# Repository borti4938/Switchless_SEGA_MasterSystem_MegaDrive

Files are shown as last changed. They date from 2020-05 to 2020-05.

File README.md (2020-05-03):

### Switchless Mods for SEGA MasterSystem and MegaDrive
---

This is a collection of earlier projects. These projects are not under development anymore. Documentation is rather simple and can be found in source code comments in most cases.

Please don't write me for any support. Please reach out to community forums and use the knowledge and experiences there.

Best Regards, Peter

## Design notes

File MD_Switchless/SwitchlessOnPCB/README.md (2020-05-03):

This small subprject is not initialted be myself. All thanks to this go to user _ArcadeTV_ and user _wshadow_; both members of the [Circuit-Board.de](https://circuit-board.de/forum/) community.
So what is this?

Histroy
---

Once I started designing my own switchless mod for the Sega Mega Drive, ArcadeTV drew a printed circuit board.
Although I was not ready with the implementation, ArcadeTV [published the PCB on circuit-board](https://circuit-board.de/forum/index.php/Thread/14691-Mega-Drive-Mod-Platinen-RGB-Bypass-Switchless-Mod-Mega-Amp/).  
This board is available in this repository.

Time was running and I lost the focus to this PCB.
Instead I made design decisions which made PCB pinout incompatible to my code.
Reasons were being pin compatible to [Sebs popular code](https://knzl.at/saturnmod/), which is used for Multi-BIOS extension on the MegaCD as well as the [build-in-game project](https://github.com/borti4938/MD-Build-In-Game).
The code went into a final state as it is presented in the top-folder here in the repository.
Another long time period passed by.

CiBo user wshadow [picked up both](https://circuit-board.de/forum/index.php/Thread/14691-Mega-Drive-Mod-Platinen-RGB-Bypass-Switchless-Mod-Mega-Amp/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) - the PCB and code - and made both compatible again.
He worked hard, learned assembler, and finally made it.
I reviewed the changes and now publish code and PCB.

Notes
---

I don't own a Mega Drive!
So please be patient if there are any misstakes in the text comming from my misunderstanding.

### PCB

PCB is made with EAGLE and has two layers.
I tested to upload the PCB on OSHPark and it works.
Of course, you can also use any other PCB manufacturer you want.

### Parts for PCB and Installation

- 1x RND 1500805Y1041
- 1x BAT 54A SMD
- 1x PIC 16F630-I/SL
- 2x SMD-0805 1,0K
- 1x RND 0805 1 20K
- 2x SMD-0805 220
- 1x RG-LED or RGB-LED with 3mm or 5mm head  
  For installation, Code supports both common anode and common cathod LEDs

### Code

The code is made for the PIC16F630.
There is an ICSP header on the PCB.

### Additional notes

Additional notes can be found in the top comment section of the *.asm file.

### Feedback

Feedback is very welcome!

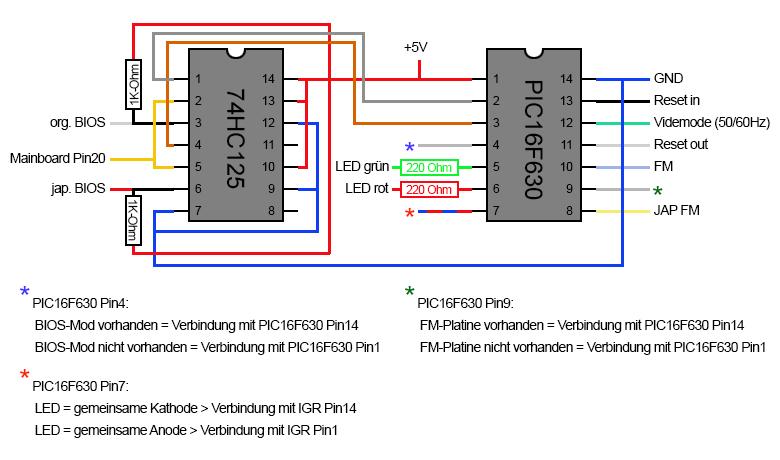
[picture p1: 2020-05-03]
MS_FM_BIOS/SMS-Mod.jpg

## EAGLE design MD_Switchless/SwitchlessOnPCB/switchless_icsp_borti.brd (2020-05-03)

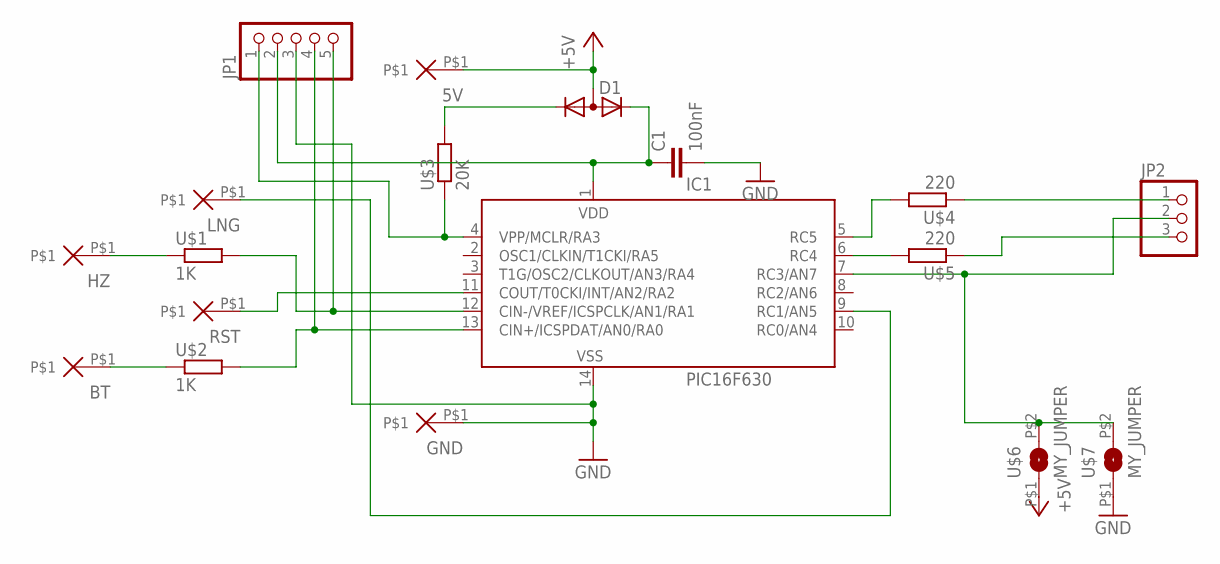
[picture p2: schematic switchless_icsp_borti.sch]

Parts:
5V: PAD; PADS
BT: PAD; PADS
C1: 100nF; Z0805
D1: DIODE_CA-AC__; SOT23C
GND: PAD; PADS
HZ: PAD; PADS
IC1: PIC16F630
JP1: PINHD-1X5; 1X05
JP2: PINHD-1X3; 1X03
LNG: PAD; PADS
RST: PAD; PADS
U$1, U$2: 1K; Z0805
U$3: 20K; Z0805
U$4, U$5: 220; Z0805
U$6, U$7: MY_JUMPER; MYJUMP

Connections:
+5V: 5V.P$1, D1.3 (A), U$6.P$1 (1)
GND: C1.2, GND.P$1, IC1.14 (VSS), JP1.3, U$7.P$1 (1)
unnamed: IC1.5 (RC5), U$4.2
unnamed: IC1.6 (RC4), U$5.2
unnamed: JP2.1, U$4.1
unnamed: JP2.3, U$5.1
unnamed: IC1.9 (RC1/AN5), LNG.P$1
unnamed: IC1.11 (COUT/T0CKI/INT/AN2/RA2), RST.P$1
unnamed: IC1.12 (CIN-/VREF/ICSPCLK/AN1/RA1), JP1.5, U$1.2
unnamed: IC1.13 (CIN+/ICSPDAT/AN0/RA0), JP1.4, U$2.2
unnamed: IC1.4 (VPP/MCLR/RA3), JP1.1, U$3.1
unnamed: HZ.P$1, U$1.1
unnamed: BT.P$1, U$2.1
unnamed: C1.1, D1.2 (K2), IC1.1 (VDD), JP1.2
unnamed: D1.1 (K1), U$3.2
unnamed: IC1.7 (RC3/AN7), JP2.2, U$6.P$2 (2), U$7.P$2 (2)

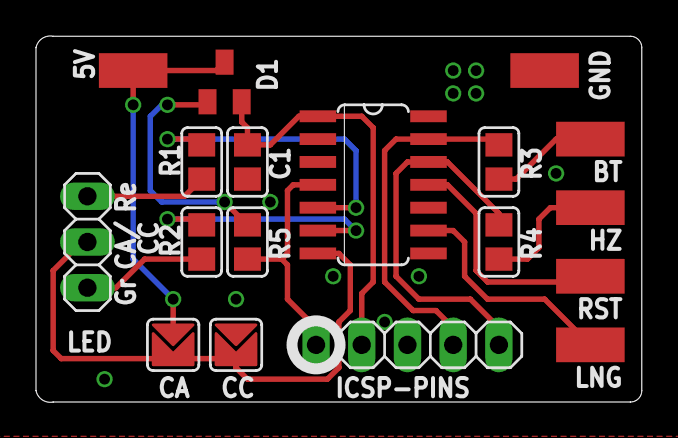
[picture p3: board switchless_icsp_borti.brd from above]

Board: 2 copper layers, 33.7 x 20.3 mm, 18 parts (0 on the bottom side), 16 nets.

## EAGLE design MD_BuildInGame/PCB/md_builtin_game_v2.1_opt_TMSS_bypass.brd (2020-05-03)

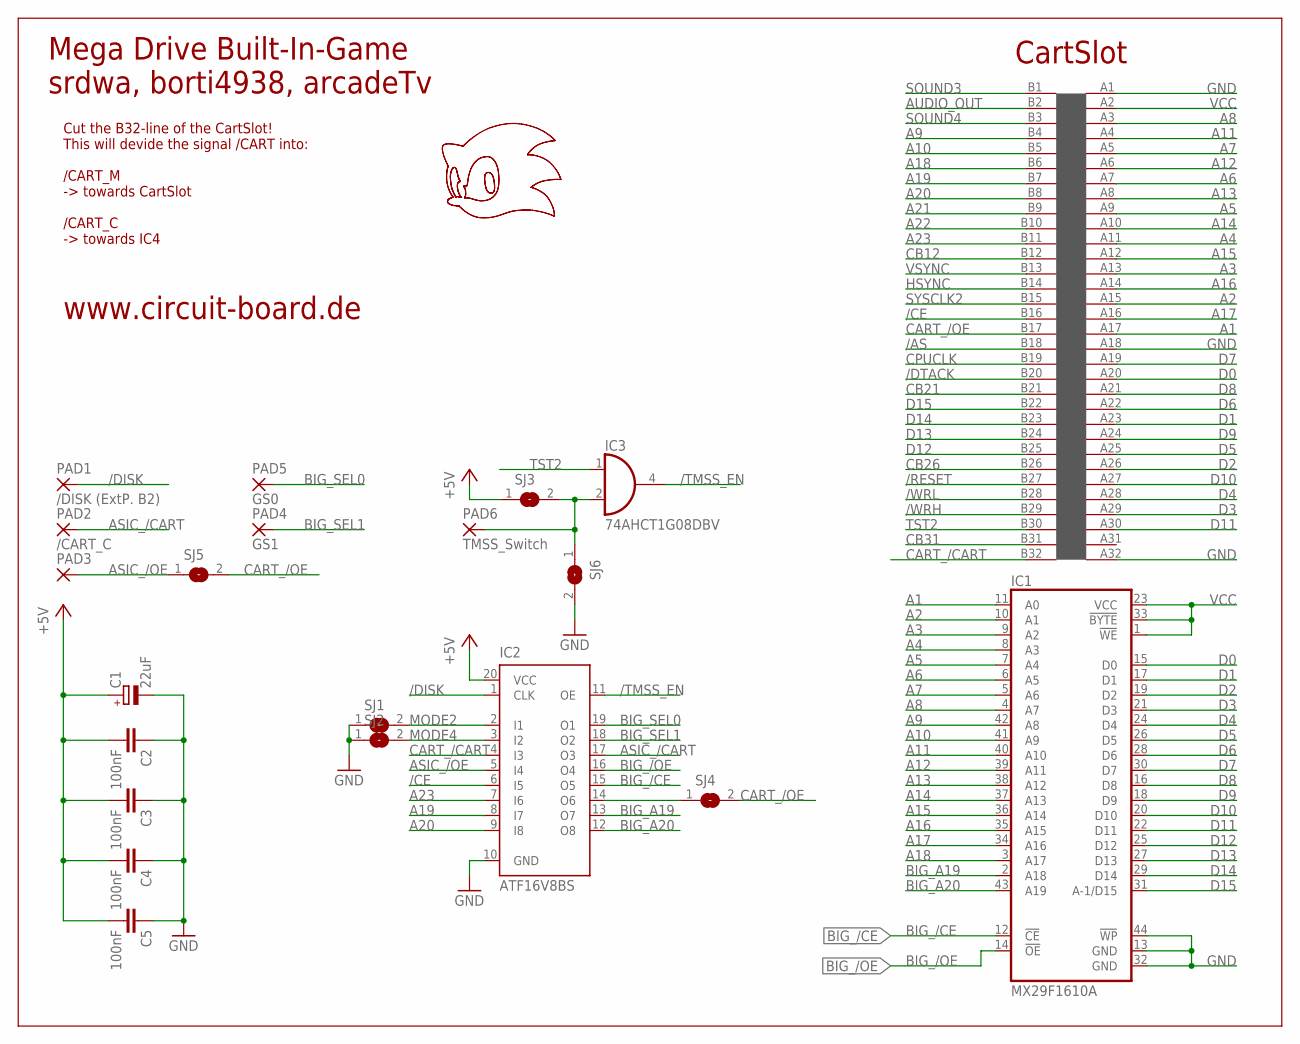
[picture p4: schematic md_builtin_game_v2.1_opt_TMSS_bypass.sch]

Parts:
C1: 22uF; SMC_C
C2, C3, C4, C5: 100nF; Z0805
IC1: MX29F1610A; SO44
IC2: ATF16V8BS; SO20L
IC3: 74AHCT1G08DBV; SOT23-5
PAD1: /DISK (ExtP. B2); SMD1,27-2,54
PAD2: /CART_C; SMD1,27-2,54
PAD3: SMD2; SMD1,27-2,54
PAD4: GS1; SMD1,27-2,54
PAD5: GS0; SMD1,27-2,54
PAD6: TMSS_Switch; SMD1,27-2,54
SJ1, SJ2, SJ3, SJ4, SJ5, SJ6: SJ
U$1: LOGO_SONIC_20MM
U$6: MEGADRIVE_EDGE_CONNECTOR

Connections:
/AS: U$6.B18
/CE: IC2.6 (I5), U$6.B16
/DISK: IC2.1 (CLK), PAD1.1
/DTACK: U$6.B20
/RESET: U$6.B27
/TMSS_EN: IC2.11 (OE), IC3.4 (O)
/WRH: U$6.B29
/WRL: U$6.B28
A1: IC1.11 (A0), U$6.A17
A2: IC1.10 (A1), U$6.A15
A3: IC1.9 (A2), U$6.A13
A4: IC1.8 (A3), U$6.A11
A5: IC1.7 (A4), U$6.A9
A6: IC1.6 (A5), U$6.A7
A7: IC1.5 (A6), U$6.A5
A8: IC1.4 (A7), U$6.A3
A9: IC1.42 (A8), U$6.B4
A10: IC1.41 (A9), U$6.B5
A11: IC1.40 (A10), U$6.A4
A12: IC1.39 (A11), U$6.A6
A13: IC1.38 (A12), U$6.A8
A14: IC1.37 (A13), U$6.A10
A15: IC1.36 (A14), U$6.A12
A16: IC1.35 (A15), U$6.A14
A17: IC1.34 (A16), U$6.A16
A18: IC1.3 (A17), U$6.B6
A19: IC2.8 (I7), U$6.B7
A20: IC2.9 (I8), U$6.B8
A21: U$6.B9
A22: U$6.B10
A23: IC2.7 (I6), U$6.B11
ASIC_/CART: IC2.17 (O3), PAD2.1
ASIC_/OE: IC2.5 (I4), PAD3.1, SJ5.1
AUDIO_OUT: U$6.B2
BIG_/CE: IC1.12 (!CE), IC2.15 (O5)
BIG_/OE: IC1.14 (!OE), IC2.16 (O4)
BIG_A19: IC1.2 (A18), IC2.13 (O7)
BIG_A20: IC1.43 (A19), IC2.12 (O8)
BIG_SEL0: IC2.19 (O1), PAD5.1
BIG_SEL1: IC2.18 (O2), PAD4.1
CART_/CART: IC2.4 (I3), U$6.B32
CART_/OE: SJ4.2, SJ5.2, U$6.B17
CB12: U$6.B12
CB21: U$6.B21
CB26: U$6.B26
CB31: U$6.B31
CPUCLK: U$6.B19
D0: IC1.15 (D0), U$6.A20
D1: IC1.17 (D1), U$6.A23
D2: IC1.19 (D2), U$6.A26
D3: IC1.21 (D3), U$6.A29
D4: IC1.24 (D4), U$6.A28
D5: IC1.26 (D5), U$6.A25
D6: IC1.28 (D6), U$6.A22
D7: IC1.30 (D7), U$6.A19
D8: IC1.16 (D8), U$6.A21
D9: IC1.18 (D9), U$6.A24
D10: IC1.20 (D10), U$6.A27
D11: IC1.22 (D11), U$6.A30
D12: IC1.25 (D12), U$6.B25
D13: IC1.27 (D13), U$6.B24
D14: IC1.29 (D14), U$6.B23
D15: IC1.31 (A-1/D15), U$6.B22
GND: C1.-, C2.1, C3.1, C4.1, C5.1, IC1.13 (GND), IC1.32 (GND), IC1.44 (!WP), IC2.10 (GND), IC3.3 (GND), SJ1.1, SJ2.1, SJ6.2, U$6.A1, U$6.A18, U$6.A32
HSYNC: U$6.B14
MODE2: IC2.2 (I1), SJ1.2
MODE4: IC2.3 (I2), SJ2.2
unnamed: IC2.14 (O6), SJ4.1
unnamed: IC3.2 (I1), PAD6.1, SJ3.2, SJ6.1
SOUND3: U$6.B1
SOUND4: U$6.B3
SYSCLK2: U$6.B15
TST2: IC3.1 (I0), U$6.B30
VCC: C1.+, C2.2, C3.2, C4.2, C5.2, IC1.1 (!WE), IC1.23 (VCC), IC1.33 (!BYTE), IC2.20 (VCC), IC3.5 (VCC), SJ3.1, U$6.A2
VSYNC: U$6.B13

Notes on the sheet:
Cut the B32-line of the CartSlot! This will devide the signal /CART into: /CART_M -> towards CartSlot /CART_C -> towards IC4
Mega Drive Built-In-Game srdwa, borti4938, arcadeTv
CartSlot
www.circuit-board.de

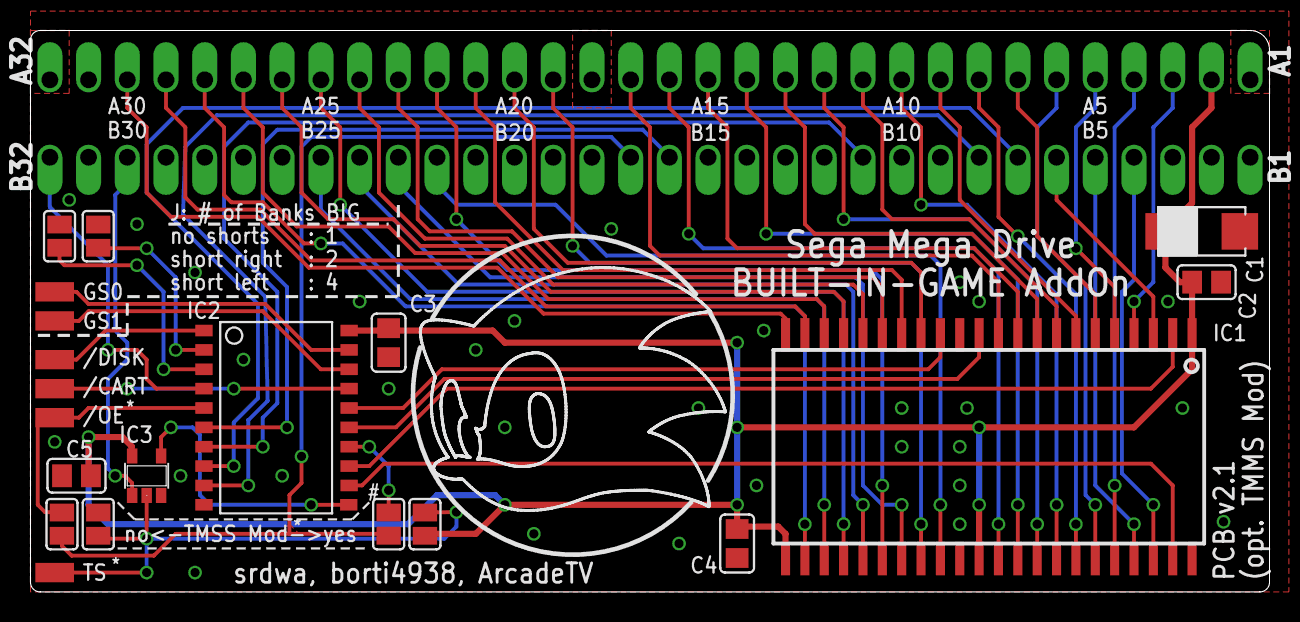
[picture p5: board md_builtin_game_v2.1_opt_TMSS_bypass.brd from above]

Board: 2 copper layers, 81.3 x 36.8 mm, 22 parts (0 on the bottom side), 57 nets.

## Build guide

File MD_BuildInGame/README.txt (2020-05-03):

Build-In Game Project for Sega Genesis / Mega Drive  
===================================================  
  
Main idea by ArcadeTV  
Development by srdwa, ArcadeTV and borti4938  
  
See logs and discussions here: http://circuit-board.de/forum/index.php/Thread/17706-Idee-Mega-Drive-mit-eingebautem-Spiel/  
  
===================================================  

This work here is still WIP!!! It has been never tested so far!!!  

===================================================  

Main idea:  
- start a game from internal rom if no device is present at the extension port or no cartridge is present  
- use indentification signals from cart slot and extension slot for detection  
- internal rom can be separated in one, two or four banks (selected by two pins)  
- bank switch is accessed by a 2bit counter  
- TMSS disable mod as described here: http://assemblergames.com/l/threads/md-genny-auto-switching-tmss-bypass-mod.19781/ can be enabled optionally  
  
===================================================  
  
ToDo:  
- test 2bit counter addition for switchless code (code by borti4938)  
- write installation tips  
  
===================================================  
  
Pinout of the PLD (G16V8) as used on the PCB:  
  
/* *************** INPUT PINS ******************** */  
PIN  1 = DISKn;     /* /DISK (ExpPort B2)                       */  
PIN  2 = ROM_Mode2; /* high/open = 1 game     , low = 2 games   */  
PIN  3 = ROM_Mode4; /* high/open = 1/2 game(s), low = 4 games   */  
                    /* low = 4 games (beats ROM_Mode2)          */  
PIN  4 = CARTn;     /* /CART (from ASIC cart slot B32,          */  
                    /*        cutted from ASIC)                 */  
PIN  5 = ASIC_OEn;  /* /OE (from ASIC; cutted from cart slot    */  
                    /*                 B17 if TMSS Mod is used) */  
PIN  6 = CEn;       /* /CE (cart slot B16)                      */  
PIN  7 = A23;       /* A23 (cart slot B11)                      */  
PIN  8 = AMSB0;     /* A19 (cart slot  B7)                      */  
PIN  9 = AMSB1;     /* A20 (cart slot  B8)                      */  
                    /* (addressbus counts from A1)              */  
  
/* *************** I/O PINS ******************** */  
PIN 19 = BIG_Sel0;   /* bank switch LSB                         */  
PIN 18 = BIG_Sel1;   /* bank switch MSB                         */  
PIN 17 = ASIC_CARTn; /* /CART (from ASIC; cutted from cart      */  
                     /*                   slot B32)             */  
PIN 16 = ROM_OEn;    /* /OE internal EEPROM (29F1610 Pin 14)    */  
PIN 15 = ROM_CEn;    /* /CE internal EEPROM (29F1610 Pin 12)    */  
PIN 14 = CART_OEn;   /* /OE cartridge (cart slot B17)           */  
PIN 13 = ROM_AMSB0;  /* A18 internal EEPROM (29F1610 Pin  2)    */  
PIN 12 = ROM_AMSB1;  /* A19 internal EEPROM (29F1610 Pin 43)    */  
PIN 11 = TMSS_ENn;   /* high = disabled, low = enabled          */  
                     /* /M3 (cart slot B30) AND TMSS-Mod_en     */

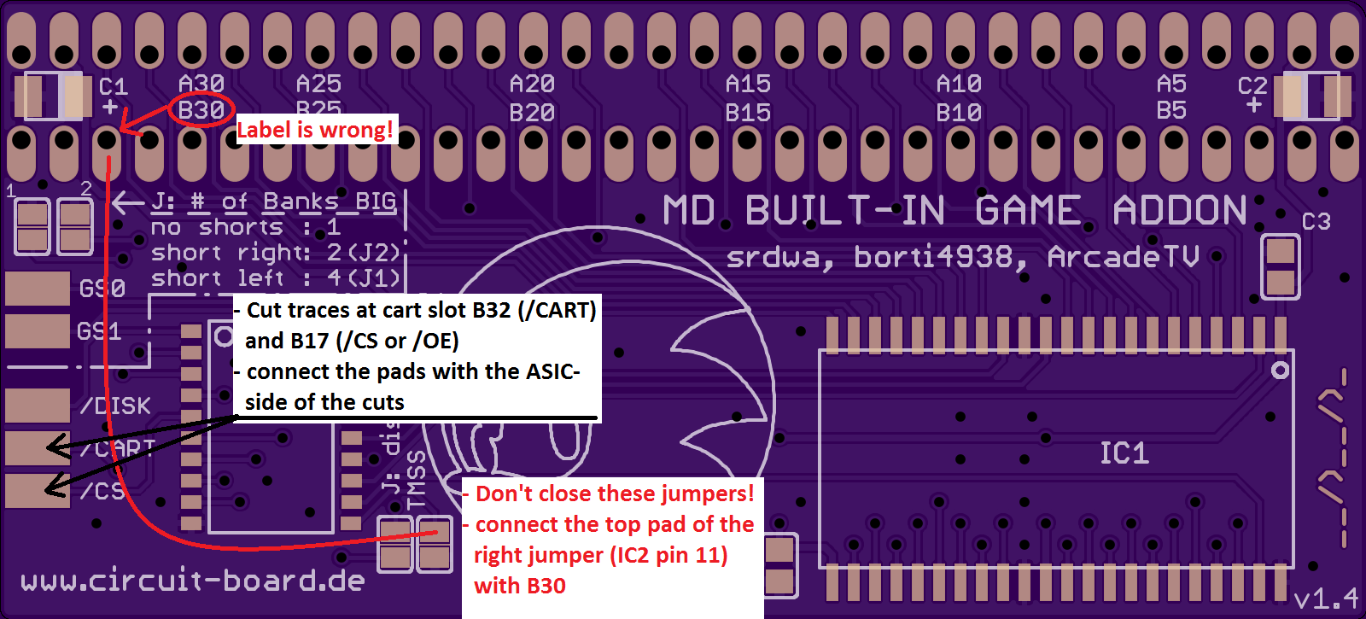
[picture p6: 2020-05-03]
MD_BuildInGame/PLD/Backup_Compatibility_PCB_V1.4/MD_BIG_V1.4_USE_TMSS_Bypass.png

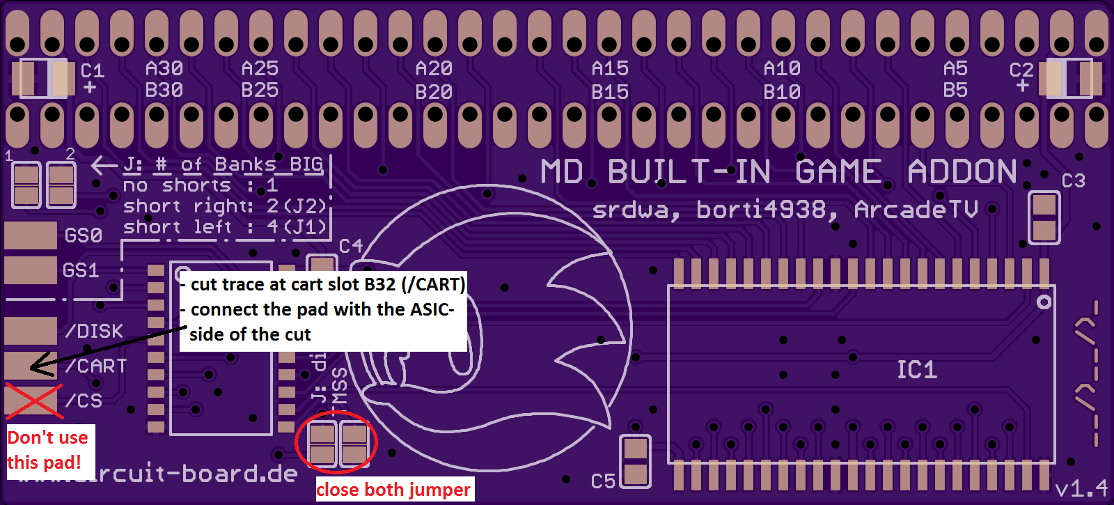
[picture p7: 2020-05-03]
MD_BuildInGame/PLD/Backup_Compatibility_PCB_V1.4/MD_BIG_V1.4_NO_TMSS_Bypass.png

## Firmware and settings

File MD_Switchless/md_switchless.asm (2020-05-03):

#include <p16f630.inc>

;
; -----------------------------------------------------------------------
;
;	Sega Mega Drive switchless mod
;
;   Copyright (C) 2016 by Peter Bartmann
;
;   This program is free software; you can redistribute it and/or modify
;   it under the terms of the GNU General Public License as published by
;   the Free Software Foundation; version 2 of the License only.
;
;   This program is distributed in the hope that it will be useful,
;   but WITHOUT ANY WARRANTY; without even the implied warranty of
;   MERCHANTABILITY or FITNESS FOR A PARTICULAR PURPOSE.  See the
;   GNU General Public License for more details.
;
;   You should have received a copy of the GNU General Public License
;   along with this program; if not, write to the Free Software
;   Foundation, Inc., 59 Temple Place, Suite 330, Boston, MA  02111-1307  USA
;
; -----------------------------------------------------------------------
;
;   pin configuration: 
;
;                         ,-----_-----.
;                     +5V |1        14| GND
;                    n.c. |2  A5 A0 13| Reset Button (in)
;                    n.c. |3  A4 A1 12| Reset Line (out)
;              /RoMC (in) |4  A3 A2 11|  Language  (out)
;       (green) LED (out) |5  C5 C0 10| /Language  (out)
;         (red) LED (out) |6  C4 C1  9|  Videomode (out)
;           LED_TYPE (in) |7  C3 C2  8| /Videomode (out)
;                         `-----------'
;
; Special purposes for pins and other common notes:
;
;   Pin 4 (/RoMC = reset on mode change, neg. logic)
;      low = RoMC on   - PIC resets console if mode has been changed
;     high = RoMC off  - in this case only the bit at pin 9 (Videomode) is changed
;                        (the bit at pin 8 is unchanged until a reset to not change the
;                         memory bank in the MegaCD MultiBIOS)
;
;   Pin 9 (Videomode)    Pin 8 (/Videomode)
;      low = 50Hz           low = 60Hz
;     high = 60Hz          high = 50Hz
;                          -> Opposite of Pin 9
;
;   Pin 11 (Language)    Pin 10 (/Language)
;      low = Japanese       low = English
;     high = English       high = Japanese
;                          -> Opposite of Pin 11
;
;   Pin 13 (Reset Button)
;     The code should be able to detect the reset type by it's own without
;     any other components.
;     
;     
; -----------------------------------------------------------------------
;
; mode description:
;
; mode 0x00 = NTSC:          60Hz, LED red     (alternative: orange)
; mode 0x01 = PAL:           50Hz, LED green   (alternative: green)
; mode 0x02 = JAP NTSC:      60Hz, LED orange  (alternative: red)
;      
; -----------------------------------------------------------------------
; Configuration bits: adapt to your setup and needs

    __CONFIG _INTRC_OSC_NOCLKOUT & _WDT_OFF & _PWRTE_OFF & _MCLRE_OFF & _CP_OFF & _CPD_OFF

use_alternative_color_scheme set 0 ; 0 = normal, 1 = alternative
; -----------------------------------------------------------------------
; macros and definitions

M_movff macro   fromReg, toReg  ; move filereg to filereg
        movfw   fromReg
        movwf   toReg
        endm

M_movlf macro   literal, toReg  ; move literal to filereg
        movlw   literal
        movwf   toReg
        endm

M_movpf macro   fromPort, toReg
        movfw   fromPort
        andlw   0x3F
        movwf   toReg
        endm

M_beff  macro   compReg1, compReg2, branch  ; branch if two fileregs are equal
        movfw   compReg1
        xorwf	compReg2, w
        btfsc   STATUS, Z
        goto    branch
        endm

M_delay_x10ms   macro   literal ; delay about literal x 10ms
                movlw   literal
                movwf   reg_repetition_cnt
                call    delay_x10ms
                endm

M_push_reset    macro
                banksel TRISA
                bcf     TRISA, RST_OUT
                banksel PORTA
                bcf     PORTA, RST_OUT
                endm

M_release_reset macro
                bsf     PORTA, RST_OUT
                banksel TRISA
                bsf     TRISA, RST_OUT
                banksel PORTA
                endm

M_set50 macro
        bcf PORTC, VIDMODE
        bsf PORTC, NVIDMODE
        endm

M_set60 macro
        bsf PORTC, VIDMODE
        bcf PORTC, NVIDMODE
        endm

M_setEN macro
        bsf PORTA, LANGUAGE
        bcf PORTC, NLANGUAGE
        endm

M_setJA macro
        bcf PORTA, LANGUAGE
        bsf PORTC, NLANGUAGE
        endm

M_skipnext_rst_pressed  macro
                        movfw   PORTA
                        xorwf   reg_reset_type, 0
                        andlw   (1<<RST_BUTTON)
                        btfss   STATUS, Z
                        endm

M_skipnext_rst_notpressed   macro
                            movfw   PORTA
                            xorwf   reg_reset_type, 0
                            andlw   (1<<RST_BUTTON)
                            btfsc   STATUS, Z
                            endm
; -----------------------------------------------------------------------

;port a
RST_BUTTON  EQU 0
RST_OUT     EQU 1
LANGUAGE    EQU 2
NRoMC       EQU 3

;port c
NLANGUAGE   EQU 0
VIDMODE     EQU 1
NVIDMODE    EQU 2
LED_TYPE    EQU 3
LED_RED     EQU 4
LED_GREEN   EQU 5

; registers
reg_overflow_cnt    EQU 0x20
reg_repetition_cnt  EQU 0x21
reg_current_mode    EQU 0x30
reg_previous_mode   EQU 0x31
reg_reset_type      EQU 0x40
reg_first_boot_done EQU 0x41

; codes and bits
code_ntsc           EQU 0x00
code_pal            EQU 0x01
code_jap            EQU 0x02

mode_overflow       EQU 0x03
bit_language        EQU 1
bit_videomode       EQU 0


code_led_off    EQU 0x00
code_led_green  EQU (1<<LED_GREEN)
code_led_red    EQU (1<<LED_RED)
code_led_orange EQU code_led_green ^ code_led_red

code_led_invert EQU code_led_green ^ code_led_red

delay_10ms_t0_overflows EQU 0x14    ; prescaler T0 set to 1:2 @ 4MHz
repetitions_100ms       EQU 0x0a
repetitions_200ms       EQU 0x14
repetitions_260ms       EQU 0x1a
repetitions_mode_delay  EQU 0x4a    ; around 740ms

; -----------------------------------------------------------------------

; code memory
 org    0x0000
    clrf    STATUS  ; 00h Page 0, Bank 0
    nop             ; 01h
    nop             ; 02h
    goto    start   ; 03h begin program / Initializing

 org    0x0004  ; jump here on interrupt with GIE set (should not appear)
    return      ; return with GIE unset

 org    0x0005
idle
    bcf     INTCON, RAIF
    M_skipnext_rst_pressed
    sleep

check_rst
    call    delay_10ms                      ; software debounce
    call    delay_10ms                      ; software debounce
    M_skipnext_rst_pressed
    goto    idle

    call    setled_off
    M_movlf repetitions_mode_delay, reg_repetition_cnt

check_rst_loop
    call    delay_10ms
    M_skipnext_rst_pressed
    goto    doreset
    decfsz  reg_repetition_cnt, 1
    goto    check_rst_loop
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

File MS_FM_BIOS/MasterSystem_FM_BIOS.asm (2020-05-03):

#include <p16f630.inc>

;
; -----------------------------------------------------------------------
;
;	Sega Master System switchless mod
;   supports:   Dual-BIOS (Eu and Jap) - needs an electrinic switch,
;                                        e.g., using a 74*125
;               FMSEB-PCB from etim - see link below
;
;   Copyright (C) 2013 by Peter Bartmann
;
;   This program is free software; you can redistribute it and/or modify
;   it under the terms of the GNU General Public License as published by
;   the Free Software Foundation; version 2 of the License only.
;
;   This program is distributed in the hope that it will be useful,
;   but WITHOUT ANY WARRANTY; without even the implied warranty of
;   MERCHANTABILITY or FITNESS FOR A PARTICULAR PURPOSE.  See the
;   GNU General Public License for more details.
;
;   You should have received a copy of the GNU General Public License
;   along with this program; if not, write to the Free Software
;   Foundation, Inc., 59 Temple Place, Suite 330, Boston, MA  02111-1307  USA
;
; -----------------------------------------------------------------------
;
;   pin configuration: 
;
;                         ,-----_-----.
;                     +5V |1        14| GND
;      /BIOS_EU  (in/out) |2  A5 A0 13| /RESET (in) (from Reset Button)
;      /BIOS_JAP (in/out) |3  A4 A1 12| VIDEOMODE (out) (50/60Hz)
;      /BIOS_SUPP    (in) |4  A3 A2 11| /RESET (in/out) (line to Console)
;       (green) LED (out) |5  C5 C0 10| /FMSEB_EN (in/out) 
;         (red) LED (out) |6  C4 C1  9| /FMSEB_SUPP (in)
;           LED_TYPE (in) |7  C3 C2  8| /JFMSEB_EN (in/out)
;                         `-----------'
;
; Special purposes for pins:
;
;   Pin 4 (/BIOS_SUPP) sets the support for possible BIOS-pack
;      low = BIOS-pack is present - you shall connect pin 2 (/BIOS_EU) and
;                                   pin 3 (/BIOS_JAP) to pin 20 of the current
;                                   BIOS-chip
;      high = BIOS-pack is not present - pin 2 and pin 3 stay in input mode with
;										 weak pull-ups enabled
;
;   Pin 7 (LED_TYPE) sets the output mode for the LED pins
;   (must be tied to either level):
;      low  = common cathode
;      high = common anode   (output inverted)
;
;   Pin 9 (/FMSEB_SUPP) sets the support for possible BIOS-pack
;      low = FMSEB is present - you shall connect pin 8 (/JFMSEB_EN) and 
;                               pin 10 (/FMSEB_EN) to the corresponding pins of
;                               the Sega Master System FM Sound Expansion Board
;      high = FMSEB is not present - you should not connect pin 8 and pin 10
;                                    to anything else as they stay in output
;                                    mode
;
; more information about the FMSEB:
; http://members.iinet.net.au/~stinkyfist/reviletim/smsfm/smsfm.html
;
; more information about the BIOS pack:
; http://www.smspower.org/forums/viewtopic.php?t=10908
;
; -----------------------------------------------------------------------
;
; mode description:
;
; mode 1 = PAL:           50Hz, LED green,
;                         jap. BIOS not active, FMSEB not active
;
; mode 2 = NTSC:          60Hz, LED red,
;                         jap. BIOS not active, FMSEB not active
;
; mode 3 = Fake JAP NTSC: 60Hz, LED orange,
;                         jap. BIOS not active, FMSEB with FM_EN#-Signal active
;
; mode 4 = JAP NTSC:      60Hz, LED orange,
;                         jap. BIOS active, FMSEB with JPFM_EN#-Signal active
;
;
;
; NB: - All four modes are available if the FMSEB is present (pin 9 on low).
;     - The jap. BIOS can only be activated if the BIOS pack is present
;       (pin 4 on low).
;     - If mode 3 and 4 are available the LED flashes three times. If the 
;       FMSEB is not present but the BIOS pack, i.e., mode 1, 2 and 4 are
;       available, the LED does not flash.
;     - If there is a mode change, where the BIOS- or the FMSEB mode is also
;       changed, the console requires a hard reset
;       (off and on over the power button).
;       If this is needed the console shows you you have to do so by flashing
;       the LED.
;       (current color -> off -> red -> green -> orange -> off -> current color)
;       Mode changes between 50Hz and 60Hz are done while the console is
;       running.
;      
; -----------------------------------------------------------------------
; Configuration bits: adapt to your setup and needs

    __CONFIG _INTRC_OSC_NOCLKOUT & _WDT_OFF & _PWRTE_OFF & _MCLRE_OFF & _CP_OFF & _CPD_OFF

; -----------------------------------------------------------------------
; macros and definitions

M_movff macro   fromReg, toReg  ; move filereg to filereg
        movfw   fromReg
        movwf   toReg
        endm

M_movpf macro   fromPORT, toReg ; move PORTx to filereg
        movfw   fromPORT
        andlw   0x3f
        movwf   toReg
        endm

M_movlf macro   literal, toReg  ; move literal to filereg
        movlw   literal
        movwf   toReg
        endm

M_beff  macro   compReg1, compReg2, branch  ; branch if two fileregs are equal
        movfw   compReg1
        xorwf	compReg2, w
        btfsc   STATUS, Z
        goto    branch
        endm

M_bepf  macro   compPORT, compReg, branch   ; brach if PORTx equals compReg (ignoring bit 6 and 7)
        movfw   compPORT
        xorwf   compReg, w
        andlw   0x3f
        btfsc   STATUS, Z
        goto    branch
        endm

M_belf  macro   literal, compReg, branch  ; branch if a literal is stored in filereg
        movlw   literal
        xorwf	compReg, w
        btfsc   STATUS, Z
        goto    branch
        endm

M_celf  macro   literal, compReg, call_func  ; call if a literal is stored in filereg
        movlw   literal
        xorwf	compReg, w
        btfsc   STATUS, Z
        call    call_func
        endm

M_delay_x10ms   macro   literal ; delay about literal x 10ms
                movlw   literal
                movwf   reg_repetition_cnt
                call    delay_x10ms
                endm

M_push_reset    macro
                banksel TRISA
                bcf     TRISA, NRESET_OUT
                banksel PORTA
                bcf     PORTA, NRESET_OUT
                endm

M_release_reset macro
                bsf     PORTA, NRESET_OUT
                banksel TRISA
                bsf     TRISA, NRESET_OUT
                banksel PORTA
                endm

M_setBIOS_EU    macro
                banksel TRISA
                bcf     TRISA, NBIOS_EU
                bsf     TRISA, NBIOS_JAP
                banksel PORTA
                bcf     PORTA, NBIOS_EU
                endm

M_setBIOS_JAP   macro
                banksel TRISA
                bcf     TRISA, NBIOS_JAP
                bsf     TRISA, NBIOS_EU
                banksel PORTA
                bcf     PORTA, NBIOS_JAP
                endm
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
